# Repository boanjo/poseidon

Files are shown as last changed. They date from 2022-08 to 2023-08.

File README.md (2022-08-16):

# poseidon
Poseidon - is a modular control setup for your garden pond for sensors and switches. Monitoring is done with the TICK stack (Telegraf, Influxdb, Chronograf and Kapacitor) accompanied by a python Flask webserver for the control and quick overview. All is (in my setup) running on a raspberry PI 4. The influxdb creates some CPU spikes but there is plenty of power over to serve the relevant stuff and UI experience is smooth. I used to run it on a RPI 3B but that was pushing the limits a bit (both memory and CPU) at least for the influxdb database.

The application is built mainly of 5 parts (For a deeper description use the READMEs below) but each individual service can be used standalone with some tweaking:
* [Fishfeeder](https://github.com/boanjo/poseidon/tree/main/fishfeeder/README.md) 
* [Water Control ](https://github.com/boanjo/poseidon/tree/main/water_control/README.md) with level and tap (including watering of the garden plants)
* [Web Server](https://github.com/boanjo/poseidon/tree/main/web_app/README.md) instance
* [Water Quality - Atlas scientific sensors](https://github.com/boanjo/poseidon/tree/main/water_quality/README.md) in custom casing and mounted in a Sieve filter
* [Pond Control](https://github.com/boanjo/poseidon/tree/main/pond_control/README.md) which is the "controller" in this setup 

The interaction with the pond is mainly done via the web app where you can control timers or interactive feeding, water on/off etc. For more details and long term trends you have that in the Chronograf or Grafana which visualize the DB data. Chronograf has a few nice predefined dashboards both for RPI resource (CPU, mem,...) usage and also the sensor values from the pond. Kapacitor is not really used at all and you can disable it if wanted as the pond_control is doing some of it's work. Telegraph is mainly used to collect the resource usage.

Overview!

All services are communicating through a MQTT (mosquitto) gateway (also running on the RPI). The Fishfeeder firmware is running on a Wemos D1 mini over wifi, the water quality on a Arduino UNO and the water control on an Arduino Nano 

The services are started using docker composer so you can update the docker-compose.yml to suite your needs. 

Not all days are sunny!

Pond!

## Howto start
* First you need to decide if you want to have all the parts and sensors. All services should be ok with that no values at all are bing pushed but there might be hardcoded assumptions (like in the web app) that you at some point will get ORP and PH etc.
* If you are building sensors like the water_control or simply the fishfeeder now is the time to do so and to program it's firmware (see each README for details). The fishfeeder hooks up over wifi and the water_quality and water_control with Arduino UNO and Nano. One reason for selecting different Arduinos is to get determensitic names at boot (i.e. so they don't get mixed) due to race conditions. This could have been solved in other ways but it's a good bonus worth knowing about.
* Now you can build and start your services (you need to install docker and docker-compose on the RPI, use something like: https://dev.to/elalemanyo/how-to-install-docker-and-docker-compose-on-raspberry-pi-1mo):

<pre><code>
  docker-compose build   #build all services based on the yml file
  docker-compose -d up   #Here you start all the services in the docker-compose.yml file daemonized so even if you exit your shell they will continue to live and start on boot
  docker ps              #check all the services up and runnig
  docker-compose logs -f #Follow the logging from all the services
</code></pre>

Here is a YouTube video explaining the Poseidon setup: https://youtu.be/6Q65v6jY_po
Here is the full Poseidon playlist: https://www.youtube.com/watch?v=6Q65v6jY_po&list=PL4uTTzIGocpXYQ4JUedOa0raxNH4VkoVa

## More details
I have 2 dashboards setup for Chronograf (one detailed/all data for the last 3 days and one downsampled for the last moth). It's quite easy to add your own graphs based on the influxdb data, but if you want to reuse them you can:
* Download the json files from the repo and drag and drop them in Chronograf under "Dashboards->Import Dashboards".
* Headless from your RPI you can install curl and then import one json a t a time with:
  * curl -i -X POST -H "Content-Type: application/json" http://localhost:8888/chronograf/v1/dashboards -d pc_dashboard.json
  * curl -i -X POST -H "Content-Type: application/json" http://localhost:8888/chronograf/v1/dashboards -d pc_dashboard_downsampled.json

Here is what you can get from the detailed dashboard (retention period 3 days):
Dashboard

Here is what you can get from the resource (Click in Chronograf in the left column "Host List"):
Host resource usage

Poseidon is licensed under GNU General Public License v3.0 or later

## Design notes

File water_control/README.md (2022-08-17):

# Water Control

The water control is built from a water level sensor (2 alternatives below) a few solenoids (one for the pond and pone for the garden plants micro drip system) for adding tap water and also measuring the water amount used. You need to print a few parts with your 3D printer. I'm using PETG with support on most of the printouts so that it can resist the outdoor UV. I.m just doing basic sanding (paper and file) and then put some spray paint on it to look nice.

For the water level control i have 2 differnt solutions, where the first one is what i currently use (see alternative 2 at the bottom - most parts are common):
## Alternative 1: KUS liquid level sensor
The sensor has a magnet in the floating piece which controls reed switches inside the steel rod to output different resistance at differnt levels. I'm using European standard sensor where the resistance is between 0-180ohm and it's priced at ~20$. To make the two solutions compatible i've added a resistance to the outer two pins as the fixed reference in a voltage divider (see below). Even if the accuracy for the sensors is 21mm (the step between the reed switches) you can make the level full/low toggle on a +-5mm accuracy due the nature of the reed switches. I.e. when the level goes down the reed switch will continue to be activated for maybe 5mm until the next lower one gets activated. Same goes in the other direction so this means that the accuracy for the range where values toogle between is 10mm or less. So just set min and max between those levels and you are good to go. Of course if you want to use the sensor for detailed monitoring of the level you will not get better than 21mm accuracy and you should probably go for the etape solution.  
KUS liquid level sensor

An Arduino Nano is used for the regulated loop and has some auto cut off for the water in some suspicious situations. Basically a high and low threshold is built in (and can be changed) and then the water control will try to keep that level. The levels are measured at a frequency of every 3:d second (can be changed) and passes through a ringbuffer of 8 where the average is calculated from. This applies to both solutions and even if you can set the ringbuffer to something smaller you risk getting ping-ponging in case of movements from the fish or strong winds. 

Some plumbing needed for the water, 2 solenoids (2x7$) and water flow sensor (~15$). To get a good pressure and a filter i've integrated it with a gardena micro drip system (~25$). And the plumbing parts are probably another 30-40$.
Plumbing

I've hidden the water control parts in 2 cement pots. This part of the system can be left out, and the only thing i do before winter time is to attach the compressor, open all the solenoids and blow the system "clean" of water. 
Concrete

Pretty easy to hide
Hidden

For programming of the firmware i've installed the platformio cli version https://docs.platformio.org/en/latest/core/index.html on the raspberry pi. I.e. i'm running an ssh connection with for example putty or mobixterm to the RPI and edit the SW using emacs, git, ino etc directly into the cloned repo. You need to stop the docker service that is communicating with the arduino to release the serial port (e.g. "docker stop poseidon_water_control_1"), then build and upload (see the CMD file for the sequence i use "source CMD" to execute) and then start the service again ((e.g. "docker start poseidon_water_control_1").

The firmware basically consists of and serial command input handler to be able to act on commands from the controller, setting levels etc. Then there is a small interrupt function that calculates any triggers from the water flow sensor and then in the loop a (quite sketchy ;-)) conversion of ticks into liters (you probably need to calibrate it to get as good flow accuracy). The percentage level of the KUS or etape sensor is done using a voltage divider. By using the ADC value (max 1024) you can then get the relative % (For more details see the source code). Once the level reaches a low point this triggers (if auto level is on) the water solenoid to open. Once the max is reached the water stops to fill again. The sensor blindly updates all values and states every sample period which is set to default every 3 seconds (or immediately if ack is requested).   
Voltage Divider

See stl_step folder models (download and edit STEP or just print STL):
Model to mount KUS level sensor

On the RPI there is a serial2mqtt.py application running and as the name indicates it bridges between the serial commands and the mqtt GW.

You need a small proto baord (the Adafruit Perma-Proto 1/2 Sized Breadboard is a great fit) for all the connections and the Arduino nano, schematics here. The RPI needs a standard RPI4 power supply (i've cut mine with a pair of GX12 2 pin connectors to get it into the box). You also need a 12 transformer for the solenoids (cut in the same way but with a 3 pin to not make any misstake). Then there is one 4 pin GX12 connector for the KUS or etape.
Schematic

Notice the mounted resistor of 100ohm (needed for the voltage divider) inside the KUS level sensor to make it pin compatible with the etape (Pin 1 & 4 for Rref and middle 2,3 for Rsense i.e. the variable part)
Resistor

Everything is hosted in the same box as the RPI4
Box

Here is a video covering the Water Control with coding and usage: https://youtu.be/Q5HgJ9Mg1no

Here is a YouTube video explaining the KUS liquid level setup: https://youtu.be/7Df8thEyxGE
Here is the full Poseidon playlist: https://www.youtube.com/watch?v=6Q65v6jY_po&list=PL4uTTzIGocpXYQ4JUedOa0raxNH4VkoVa

## Alternative 2: Milone technology etape
The sensor is quite sensitive and this is why i have move to the float switch solution instead. I love the etape due to it's accuracy but it has broken down on me a few time too many (resistance all of a sudden goes off the datasheet range like max 2.2k is all of a sudden 9k etc) and you of course need something robust when dealing with water.
Etape

3D printed parts

See stl_step folder models (download and edit STEP or just print STL):
Model to mount etape level sensor

Here is a YouTube video explaining the etape liquid level setup: https://youtu.be/k4SEj0wbtEo

Poseidon is licensed under GNU General Public License v3.0 or later

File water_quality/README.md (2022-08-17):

# Water Quality

The water quality is monitored with a set of sensors or probes from Atlas Scientific: Temperature, PH, ORP, DO and EC probes are connected to the carrier boards mounted on a Tentacle T1 MKII. The firmware is running on an Arduino UNO 

Atlas sensors with mounting in the Sieve filter

If you don't want to go all in (these sensors + carrier boards cost in the range of $150 to much more) i think the PH and ORP are the most valuable measurments to have. I rarely look at the EC or DO values. Bu that is also because i live in a place in Sweden where the tap water quality is very good. So hard to make any recommendations there but you know my thinking at least. The temperature sensor seems good even if you can make a cheaper solution yourself.

On the RPI there is a serial2mqtt.py application running and as the name indicates it bridges between the serial commands and the mqtt GW.

The Arduino UNO firmware continously collects all the sensor values every 3 seconds and the data is continously pushed to the DB via the MQTT GW, see dashed route red:
Sensor route

For programming of the firmware i've installed the platformio cli version https://docs.platformio.org/en/latest/core/index.html on the raspberry pi. I.e. i'm running an ssh connection with for example putty or mobixterm to the RPI and edit the SW using emacs, git, ino etc directly into the cloned repo. You need to stop the docker service that is communicating with the arduino to release the serial port (e.g. "docker stop poseidon_water_quality_1"), then build and upload (see the CMD file for the sequence i use "source CMD" to execute) and then start the service again ((e.g. "docker start poseidon_water_quality_1").

You can monitor the sensor values eiter in the web_gui which shows the sensor values in real time but also with min and max range on the right side. You can also follow longer trends in either Grafana or Chronograf. This is from my default dashboards you can also import from the poseidon root dir.
Sensor Details

See stl_step folder models (download and edit STEP or just print STL):

The Tentacle T1 MKII is a great board for the carrier boards and the sensors and i really recommend it. I've made a small box (not water proof) with both a plexiglass front and a solid one.
Tentacle T1 MKII box model
Tentacle T1 MKII box
Hidden electronics

The mounting is tailored for my Sieve filter and works really well. Some of the Atlas sensors need to have a water flow to give accurate readings so this is perfect. It's also a pretty good way to hide the cables
Atlas sensors mounting model
Sieve filter

Here is a YouTube video explaining the sensors, 3D models and code for the water quality setup: https://youtu.be/J5xhtjKq1kM
Here is the full Poseidon playlist: https://www.youtube.com/watch?v=6Q65v6jY_po&list=PL4uTTzIGocpXYQ4JUedOa0raxNH4VkoVa

Poseidon is licensed under GNU General Public License v3.0 or later

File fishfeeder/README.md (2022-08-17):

# Fishfeeder

I have built a number of feeders for my koi fishes over the year (first one in 2005 ;-)) but now i i finally found a way that i think is a good balance between price, quality and build effort. You need to have a 3D printer (i guess you can order them from a printshop too). There are PETG material needed for maybe $20-30, a simple DC continously rotating servo for ~$10, a wemos D1 mini for ~$8 some sewer pipe parts (or if you want your own tank) for another ~$15. So in total you should be able to produce it with ~$50. The pellets screw is designed for 3mm pellets (it might work with other sizes but i don't know since i only use 3mm myself).

The water control is built from a water level sensor (2 alternatives below) a few solenoids (one for the pond and pone for the garden plants micro drip system) for adding tap water and also measuring the water amount used. You need to print a few parts with your 3D printer. I'm using PETG with support on most of the printouts so that it can resist the outdoor UV. I.m just doing basic sanding (paper and file) and then put some spray paint on it to look nice.

The feeder next to the reed makes it more fun for the fishes (they are hunting like crazy in the reed) but also good to avoid getting too fast into the skimmer.
The feeder
The feeder2

Here are the parts for the feeder:
PVC pipes and some 3D prints

Basic operation is like a pellets screw. The screw has a loose fit in the cylinder to reduce the fricton and there is no problem for the DC servo to rotate, pulling KOI pellets from the PVC tube.
Basic operation

The full unit except the PVC tube:
Feeder kit

I didn't rough the surface enough the first time, but now it's good. Ideally add some PVD primer or other coler with specialized adhesion.
PVC pipes and some 3D prints

See stl_step folder models (download and edit STEP or just print STL):
Fishfeeder model

Closeup

Here is a YouTube video explaining the 3D models and code for the fishfeeder: https://youtu.be/I_7Ob8AsT4w
Here is the full Poseidon playlist: https://www.youtube.com/watch?v=6Q65v6jY_po&list=PL4uTTzIGocpXYQ4JUedOa0raxNH4VkoVa

The firmware that you need to upload to the Wemos D1 mini can be done from the same RPI using a micro USB cable (unless you want to install platformio gui or cli on your laptop/desktop). The source code is quite simple and mainly default sketch for connecting to your Wifi, connect to a MQTT server and then to just listen on incoming feeding requests where the DC servo is stepped accordingly. It also reports back when ready or listen to ack requests. In order to get a specific amount in milliliter or such then just tune that with your specific fishfood (as that might differ with different pellets) to see how many steps that match. With a fishfeeder you have the luxury of feeding less but more frequently :-). 9 steps on the DC servo is the equivalent of one tablespoon i.e. 15ml so rougly 1.5ml per step. The default value in the web_app when feeding interactively is only 3 (change if you want to (in the web_app/app.py)) so one teaspoon 5ml.
* Change the WIFI settings for your router in Credentials.h or you will get a compilation error (just remove the #error when done)
* Update the mqtt_server ip address in main.cpp or you will get a compilation error (just remove the #error when done)

You don't need any board and very little soldering. Basically the 3 wires on the wemos, see schematic. The rest is mounted on the printed mounting and a 2 pol terminal connector
Schematic
Mounting

Poseidon is licensed under GNU General Public License v3.0 or later

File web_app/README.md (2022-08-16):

# Poseidon Web App

The web app is built upon python flask that is running on the RPI4. This is more than enough for a low number of users (i assume you don't expose your pond control for thousands of users ;-). Otherwise flask should be fronted with a proper WSGI webserver like nginx.

The web app uses both the influxdb and mqtt to gather the data presented in the GUI. While active it listens to new sensor values (i.e. real time) but also shows the min and max values today for all sensors. 

If you press the Debug button in the right top corner you will be adding all the raw MQTT messages that are coming on the bus. Press it once more to toggle off or your web gui will be sluggish as it just appends divs to the page. The chronograf dashboards can be reached via the top left button

To open the dashboard just navigate to the ipaddress and the port you choose to expose in the docker-compose.yml (under web_app ports).  i.e. http://localhost:8080
Dashboard

As the button says "Timers" i guess it's no surprise that here you can modify the timers/alarms for feeding the fishes, starting sprinklers etc.
Timers

Feel free to update the web app to your liking. I wanted it clean so there are not so much visual bells and whistles. See it as a boilerplate that does the job.

Here is a YouTube video giving an overview of the code for the web_app: https://youtu.be/K_MTeVfbo9E
Here is the full Poseidon playlist: https://www.youtube.com/watch?v=6Q65v6jY_po&list=PL4uTTzIGocpXYQ4JUedOa0raxNH4VkoVa

Poseidon is licensed under GNU General Public License v3.0 or later

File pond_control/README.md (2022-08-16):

# Pond Control

This is a small piece of python software that continously keep track of timeouts (alarms) to feed or turn on water etc. It also interacts with the influxdb and stores subscribed mqtt topics (all pc/# topic) into the database. This is something that you normally can make with the telegraph service but the configuration for it got too complicated so it was easier to implement in a few lines of python. So even if it is small it's the most central piece of the SW stack i.e. the controller. 

Overview

Poseidon is licensed under GNU General Public License v3.0 or later

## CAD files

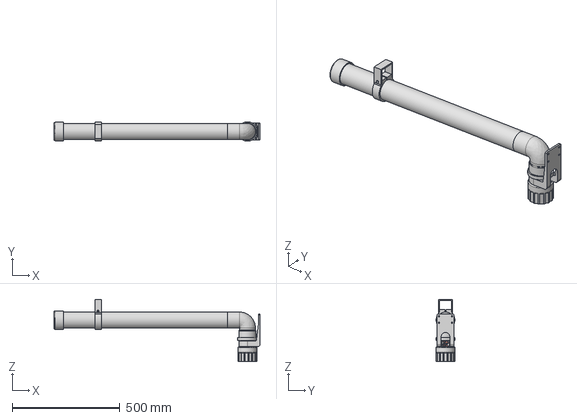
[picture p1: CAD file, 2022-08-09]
fishfeeder/stl_step/FishFeeder Tube straight v10.step
954.6 x 90.0 x 288.0 mm

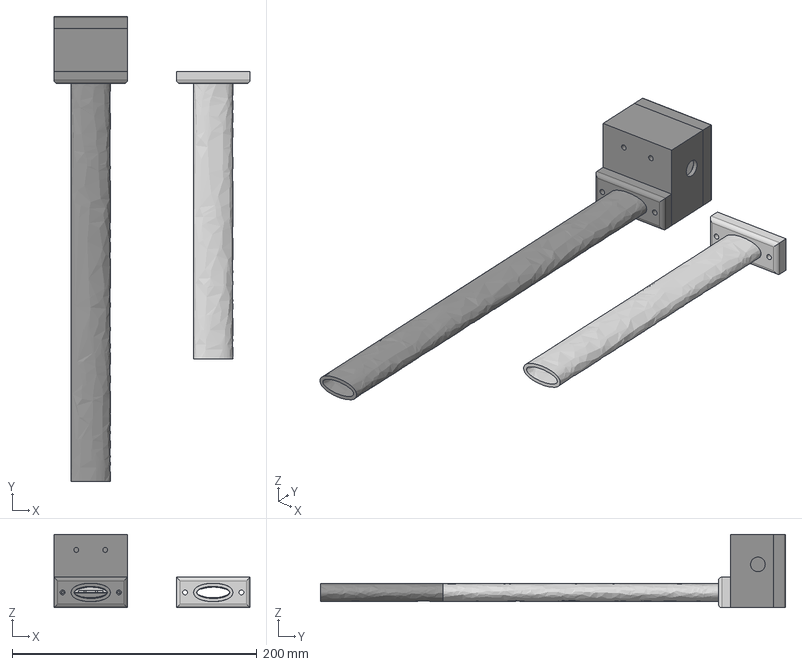
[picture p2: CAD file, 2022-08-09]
water_control/stl_step/Water Level Sensor v10.step
160.0 x 380.0 x 60.0 mm

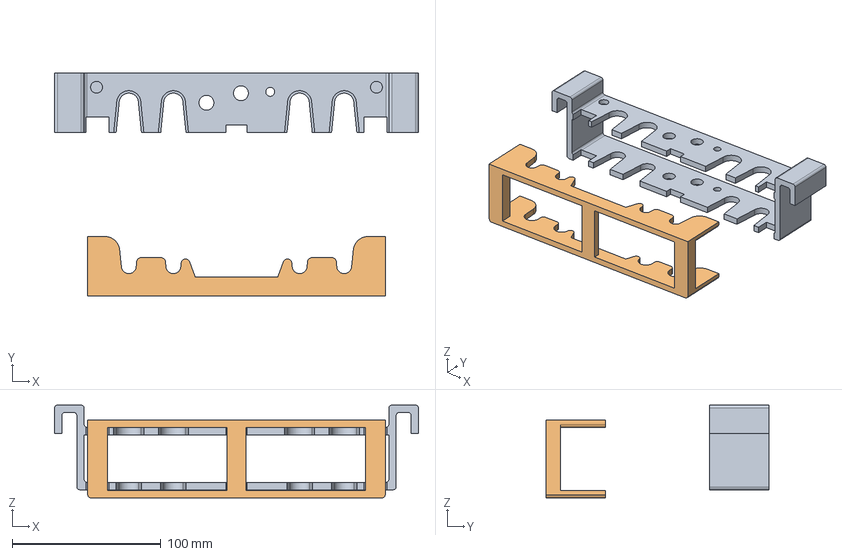
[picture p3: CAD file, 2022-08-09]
water_quality/stl_step/Probe mounting v1.step
245.0 x 150.0 x 62.5 mm

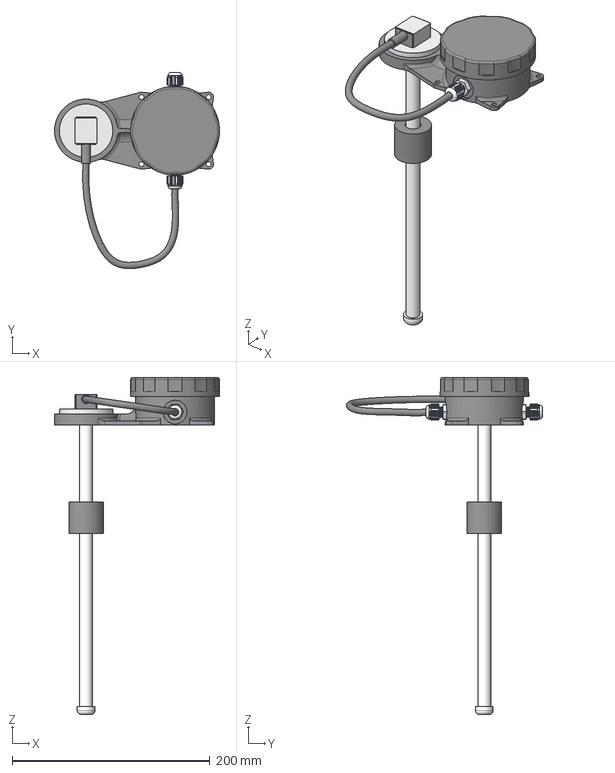
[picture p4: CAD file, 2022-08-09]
water_control/stl_step/KUS level sensor v9.step
167.0 x 198.6 x 341.0 mm

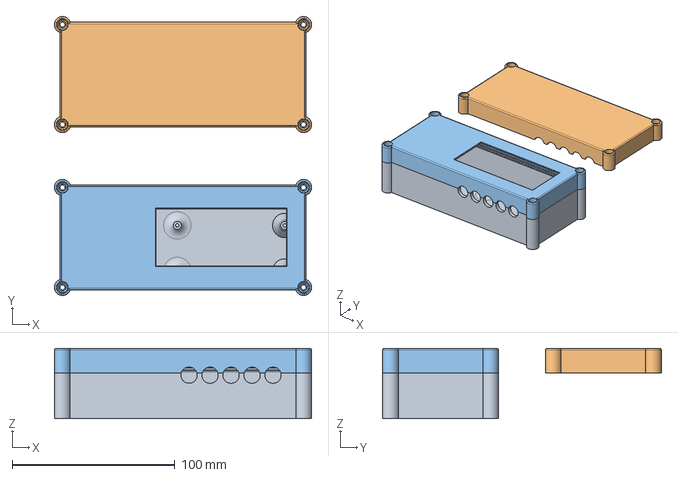
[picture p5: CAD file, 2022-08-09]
water_quality/stl_step/water_quality v5.step
158.0 x 171.3 x 43.0 mm

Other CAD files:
fishfeeder/stl_step/FishFeeder Tube straight v10.stl
water_control/stl_step/KUS level sensor v9.stl
water_control/stl_step/Water Level Sensor v10.stl
water_quality/stl_step/Probe mounting v1.stl
water_quality/stl_step/water_quality v5.stl

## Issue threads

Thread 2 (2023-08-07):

fishfeeder not working well with 6mm pellets

dhaude, 2023-08-07:
@boanjo
I already started my own design based on the sewer pipes you are using as well. After finding your project I stopped my design activities and build the feeder completely on your design.
I finished it during the weekend and started first tests today.
Unfortunately I am using 6mm pellets and they cause the screw to jam and the DC-Motor is not strong enough to "crack" them.
So 2 things I've in mind now:
1. I ordered a bag 3mm pellets - hoping that those are transported smoothly
or
2. I kindly ask you to provide me with you original CAD-Design Files in order to adopt the design to the 6mm pellets - any chance?

Thank you so much for sharing your 'poseidon' project - I really like it!

boanjo, 2023-08-08:
@dhaude btw did you see the fishfeeder/stl_step/FishFeeder Tube straight v10.step file? I forgot i had already provided the model. Import the step file in fusion 360 and you should be good to go. If it still doesn't work i'm sure the 360 files can be shared. Let me know how it goes!

dhaude, 2023-08-08:
@boanjo - Ah, OK, I will try that.
My strategy is the following: I will get some 3mm pellets by tomorrow and if this goes well - I'll change to those without any changes.
I also ordered a 360 degree Servo with much higher torque and will check this as well.
Only if that will not do the job - I'll try to change the dimensions of the mechanics.
For your information: I added OTA support to your code - so debug and small SW changes can now be loaded via WiFi without going out and opening the feeder.
I also found a small Software flaw in your code - some double quotes for `clientId` were missing.
Should be:
#endif
    String payload = "{\"type\":\"periodic_wifi_mqtt\",";
    payload += "\"micros\":";
    payload += micros();
    payload += ",\"rssi\":";
    payload += rssi;
    payload += ",\"cnt_reconnect\":";
    payload += cntReconnectAttempt;
    payload += ",\"client\":\"";
    payload += clientId;
    payload += "\"}";

Thanks again for this project and have a nice day.

dhaude, 2023-08-08:
just noticed that the backslashes were not shown:

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

Closed 2023-08-09.

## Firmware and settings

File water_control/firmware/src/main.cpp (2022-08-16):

//**************************************************************************************
// Poseidon is licensed under GNU General Public License v3.0 or later
//**************************************************************************************

#include <Arduino.h>
#include <stdlib.h>
#include <ctype.h>

#define LEVEL_SENSOR_KUS   0
#define LEVEL_SENSOR_ETAPE 1

long levelSensorType = LEVEL_SENSOR_KUS;
#define WATER_LEVEL_PIN A0

// For a KUS reed swith type of sensor it's optimal to find a wanted level between two reistances (the sensor has a granularity
// of 20-22mm). If you select it carfully you can still accomplish a threshold that is within +-5mm or so. In the example below
// i have a 300mm KUS sensor which then has 13 steps(0-192 fixed resistances. so the value i want to stay at is just when it
// toggles to the second highest level 91.5% and the 3:d highest level is at 86.5%. hence i have selected min and max level as
// two values inbetween. The reed switched has a built in hysteresis. So when a reed switch gets activated it will continue to
// hold slightly longer until the next switch gets activated.
// Operations will then be: we fill until the 91.5% is reached and then stop. When the level is slowwly decreasing (remove water
// or waporize) iit will continue to hold the level at 91.5% for another 5-10mm and then toggle to 86.5%. We will then be below the
// min and once again we will fill up again. I.e. we can achieve 5-10 mm operations accuracy even if it is only 20-22mm for the
// actual sensor.
long waterLevelLow = 88;
long waterLevelHigh = 89;

#define FLOW_SENSOR_PIN 2
#define SPRINKLER_1_CONTROL_PIN 6
#define WATER_CONTROL_PIN 5

#define STATE_WATER_OFF 0
#define STATE_WATER_ON  1

#define NO_OF_LEVEL_AVERAGE_ITEMS 8

#define MODE_WATER_MANUAL 0
#define MODE_WATER_AUTOMATIC 1


float levelArray[NO_OF_LEVEL_AVERAGE_ITEMS];
long levelAvgCnt = 0;
byte waterMode = MODE_WATER_AUTOMATIC;
byte waterState = STATE_WATER_OFF;
byte sprinkler1State = STATE_WATER_OFF;
unsigned long previousMillis = 0;
unsigned long interval = 3000;
String inputString = ""; // a string to hold incoming data

volatile uint32_t flowPulses = 0;
volatile uint8_t lastFlowPinState = LOW;
long seqNo = 0;
// Interrupt is called once a millisecond, looks for any pulses from the sensor!
SIGNAL(TIMER0_COMPA_vect)
{

  uint8_t x = digitalRead(FLOW_SENSOR_PIN);

  if ((x == HIGH) && (lastFlowPinState == LOW))
  {
    //low to high transition!
    flowPulses++;
  }
  lastFlowPinState = x;
}

void useInterrupt(boolean v)
{
  if (v)
  {
    // Timer0 is already used for millis() - we'll just interrupt somewhere
    // in the middle and call the "Compare A" function above
    OCR0A = 0xAF;
    TIMSK0 |= _BV(OCIE0A);
  }
  else
  {
    // do not call the interrupt function COMPA anymore
    TIMSK0 &= ~_BV(OCIE0A);
  }
}

void setup(void)
{
  Serial.begin(115200);
  digitalWrite(WATER_CONTROL_PIN, LOW);
  pinMode(WATER_CONTROL_PIN, OUTPUT);

  digitalWrite(SPRINKLER_1_CONTROL_PIN, LOW);
  pinMode(SPRINKLER_1_CONTROL_PIN, OUTPUT);

  pinMode(WATER_LEVEL_PIN, INPUT);

  pinMode(FLOW_SENSOR_PIN, INPUT);
  digitalWrite(FLOW_SENSOR_PIN, HIGH);
  lastFlowPinState = digitalRead(FLOW_SENSOR_PIN);

  useInterrupt(true);

  Serial.println("Starting!");
}

int getSerialValue(String str)
{
  String subStr = str.substring(str.indexOf(",") + 1, str.length());
  return subStr.toInt();
}

void printState(bool state) {
  if (state)
    Serial.print("on");
  else
    Serial.print("off");
}

void loop(void)
{
  const byte strLen = 8;
  char litersStr[strLen];
  char levelStr[strLen];
  float waterLevel;
  float waterLevelAvg = 0;
  char inChar;
  boolean ack_requested = false;
  
  // USB HW serial
  if (Serial.available() > 0)
  {
    inChar = Serial.read();

    if (inChar == '{')
    {
      inputString = "";
    }
    else if (inChar == '}')
    {
      if (inputString.length() > 0)
      {

        if (inputString.indexOf("water_level_low") != -1)
        {
          waterLevelLow = getSerialValue(inputString);
        }
        else if (inputString.indexOf("water_level_high") != -1)
        {
          waterLevelHigh = getSerialValue(inputString);
        }
        else if (inputString.indexOf("ack_request") != -1)
        {
          seqNo = getSerialValue(inputString);
	  ack_requested = true;
        }
        else if (inputString.indexOf("water") != -1)
        {
	  String subCmd = inputString.substring(inputString.indexOf(",")+1, inputString.length());
          if (subCmd.indexOf("off") != -1)
          {
            digitalWrite(WATER_CONTROL_PIN, LOW);
            waterState = STATE_WATER_OFF;
          }
          else if (subCmd.indexOf("on") != -1)
          {
            digitalWrite(WATER_CONTROL_PIN, HIGH);
            waterState = STATE_WATER_ON;
          }
        }
        else if (inputString.indexOf("auto_level") != -1)
        {
	  String subCmd = inputString.substring(inputString.indexOf(",")+1, inputString.length());

	  if(subCmd.indexOf("off") != -1)
          {
            waterMode = MODE_WATER_MANUAL;
          }
          else if (subCmd.indexOf("on") != -1)
          {
            waterMode = MODE_WATER_AUTOMATIC;
          }
        }
        else if (inputString.indexOf("sprinkler1") != -1)
        {
	  String subCmd = inputString.substring(inputString.indexOf(",")+1, inputString.length());
	  
	  if(subCmd.indexOf("off") != -1)
          {
            digitalWrite(SPRINKLER_1_CONTROL_PIN, LOW);
            sprinkler1State = STATE_WATER_OFF;
          }
	  else if(subCmd.indexOf("on") != -1)
          {
            digitalWrite(SPRINKLER_1_CONTROL_PIN, HIGH);
            sprinkler1State = STATE_WATER_ON;
          }
        }

        inputString = "";
      }
    }
    else
    {
      // add it to the inputString:
      inputString += inChar;
    }
  }

  unsigned long currentMillis = millis();

  // Handle wrap around
  if (currentMillis < previousMillis)
  {
    previousMillis = currentMillis;
  }
  if (((currentMillis - previousMillis) > interval) || ack_requested)
  {
    // save the last time you blinked the LED
    previousMillis = currentMillis;

    // Calculate amount of added water in liters
    float liters = flowPulses;
    liters /= 8.1;
    liters -= 6;
    liters /= 60.0;

    if (liters < 0)
      liters = 0;
    dtostrf(liters, 7, 1, litersStr);

    // Read the KUS or etape voltage divider
    int analogLevelValue = analogRead(WATER_LEVEL_PIN);

    if(levelSensorType == LEVEL_SENSOR_KUS) {
      // KUS European level switch goes between 0-192 (or actually 0-180 according to datasheet) ohm (192 100% full)
      // Voltage divider tells us R2/(R1+R2) where R2 is the KUS variable resistance
      // and R1 is the fixed 100ohm resistance
      // So the max analog read would be 192/(192+100)*1023=673
      // So to get the percentage fill level 0-100% we can divide the analog value
      // with 6.73
      
      waterLevel = analogLevelValue / 6.73;
    } else {

      // milonetech etape (use RSense i.e. middle two pins as R2 and outer two pins (RRef) as R1
      // For an empty level (i.e. no water contact on Rsense) the two resistances should be roughly the same
      // 2.2k/(2.2k+2.2k)*1023=512 
      waterLevel = 100.0 - (analogLevelValue / 5.12);

      // As an example a completly submerged etape will have a resistance of 400ohm on RSense. This means that
      // the fill level will never reach 100% (analogLevelValue will show ~93 i.e. waterLevel = 82% (100-(93/5.12)
      // Select the level min max (waterLevelLow, waterLevelHigh) thresholds accordingly
      
      if(waterLevel < 0.0) {
	waterLevel = 0.0;
      }
    }
    
    levelArray[levelAvgCnt % NO_OF_LEVEL_AVERAGE_ITEMS] = waterLevel;
    levelAvgCnt++;

    if (levelAvgCnt >= NO_OF_LEVEL_AVERAGE_ITEMS)
    {
      for (int i = 0; i < NO_OF_LEVEL_AVERAGE_ITEMS; i++)
      {
        waterLevelAvg += levelArray[i];
      }

      waterLevelAvg = waterLevelAvg / NO_OF_LEVEL_AVERAGE_ITEMS;

      // Something is fishy, better turn off the auto mode too
      if (waterLevelAvg > 95)
      {
	if(waterMode == MODE_WATER_AUTOMATIC)
	{
	  waterMode = MODE_WATER_MANUAL;

	  digitalWrite(WATER_CONTROL_PIN, LOW);
	  waterState = STATE_WATER_OFF;
	}
      }

      if (waterMode == MODE_WATER_AUTOMATIC)
      {
        if ((waterLevelAvg < waterLevelLow) && (waterState == STATE_WATER_OFF))
        {
          digitalWrite(WATER_CONTROL_PIN, HIGH);
          waterState = STATE_WATER_ON;
        }
        else if ((waterLevelAvg > waterLevelHigh) && (waterState == STATE_WATER_ON))
        {
          digitalWrite(WATER_CONTROL_PIN, LOW);
          waterState = STATE_WATER_OFF;
        }
      }
    }

    dtostrf(waterLevelAvg, 5, 1, levelStr);

   
    //######### SERIAL SEND ################

    Serial.print("{analog_level_value,");
    Serial.print(analogLevelValue);
    Serial.println("}");

    Serial.print("{flow,");
    for(int i = 0; i < strLen; i++) {
      if(litersStr[i] == '\0')
	break;
      if(!isspace(litersStr[i])) {
	Serial.print(litersStr[i]);
      }
    }      
    Serial.println("}");
    Serial.print("{level,");
    for(int i = 0; i < strLen; i++) {
      if(levelStr[i] == '\0')
	break;
      if(!isspace(levelStr[i])) {
	Serial.print(levelStr[i]);
      }
    }      
    Serial.println("}");

    Serial.print("{auto_level,");
    printState(waterMode == MODE_WATER_AUTOMATIC);
    Serial.println("}");

    Serial.print("{water,");
    printState(waterState == STATE_WATER_ON);
    Serial.println("}");

    Serial.print("{sprinkler1,");
    printState(sprinkler1State == STATE_WATER_ON);
    Serial.println("}");

    if(ack_requested) {
      Serial.print("{ack,");
      Serial.print(seqNo);
      Serial.println("}");
    }
  }
}

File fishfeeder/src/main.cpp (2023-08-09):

//**************************************************************************************
// Poseidon is licensed under GNU General Public License v3.0 or later
//**************************************************************************************

#include <ESP8266WiFi.h>
#include <PubSubClient.h>
#include <Credentials.h>

#define DEBUG 1
int servoPin = D3;

#error Remove this line once you have updated the IP address below
const char *mqtt_server = "192.168.1.9"; // @TODO change this to the IP of your MQTT server


const char *topic = "pc";                // The mqtt root topic
String pubTopic;

long timeBetweenMessages = 1000 * 5 * 1;
long timeBetweenReconnectAttempts = 1000 * 5;

WiFiClient espClient;
PubSubClient client(espClient);
long lastMsg = 0;
long lastReconnectAttempt = 0;
long cntReconnectAttempt = 0;
String clientId = "fishfeeder";
int status = WL_IDLE_STATUS; // the starting Wifi radio's status

void setup_wifi()
{
  delay(10);
  // We start by connecting to a WiFi network
  Serial.println();
  Serial.print("Connecting to ");
  Serial.println(WIFI_SSID);
  WiFi.begin(WIFI_SSID, WIFI_PW);
  while (WiFi.status() != WL_CONNECTED)
  {
    delay(500);
    Serial.print(".");
  }
  Serial.println("");
  Serial.println("WiFi connected");
  Serial.println("IP address: ");
  Serial.println(WiFi.localIP());
}

#define MAX_QUEUE_ITEMS 8
int feedIndex = 0;
int insertIndex = 0;
int numFeedItems = 0;
int feedQueue[MAX_QUEUE_ITEMS];
boolean stateFeeding = false;
int pulseCount = 0;
long totalFeedCount = 0;
long pinStartMicros = 0;

void callback(char *topic, byte *payload, unsigned int length)
{
  Serial.print("Message arrived [");
  Serial.print(topic);
  Serial.print("] ");
  String msg = "";
  for (unsigned int i = 0; i < length; i++)
  {
    //Serial.print((char)payload[i]);
    msg += (char)payload[i];
  }
  Serial.println(msg);

  // Switch on the LED if an 1 was received as first character
  if (strcmp(topic, "pc/fishfeeder/in/feed") == 0)
  {
    if (msg.indexOf("{value:") != -1)
    {
      int value = atoi(msg.substring(msg.indexOf(":") + 1, msg.indexOf("}")).c_str());
      if (numFeedItems < MAX_QUEUE_ITEMS)
      {
        Serial.print("Feeding! numFeedItems = ");
        Serial.println(numFeedItems);

        // x8 to translate ml to pulses (depending on the feeding screw dimension)
        feedQueue[insertIndex] = value * 8;
        numFeedItems++;
        insertIndex++;
        if (insertIndex >= MAX_QUEUE_ITEMS)
        {
          insertIndex = 0;
        }
        Serial.print("Feeding!");
      }
      else
      {
        Serial.println("Max Queue reached!!!!");
      }
    }
    else
    {
      Serial.println("Unknown sub command");
    }
  }
  else if (strcmp(topic, "pc/fishfeeder/in/ack_request") == 0)
  {
    if (msg.indexOf("{value:") != -1)
    {
      int value = atoi(msg.substring(msg.indexOf(":") + 1, msg.indexOf("}")).c_str());
      String topic = pubTopic;
      topic += "/ack";
      String valStr = "{\"value\":";
      valStr += value;
      valStr += "}";
      client.publish((char *)topic.c_str(), (char *)valStr.c_str(), true);
    }
    else
    {
      Serial.println("Unknown sub command");
    }
  }
  else
  {
    Serial.print("Unknown topic: ");
    Serial.println(topic);
  }
}

void reconnect()
{

  if (WiFi.status() != WL_CONNECTED)
  {
    setup_wifi();
  }

  Serial.print("Attempting MQTT connection...");

  // Attempt to connect
  if (client.connect(clientId.c_str()))
  {
    Serial.println("connected");
    // Once connected, publish an announcement...
    client.publish(topic, ("connected " + clientId).c_str(), true);
    // ... and resubscribe
    // topic + clientID + in
    String subscription;
    subscription += topic;
    subscription += "/";
    subscription += clientId;
    subscription += "/in/#";
    client.subscribe(subscription.c_str());
    Serial.print("subscribed to : ");
    Serial.println(subscription);
  }
  else
  {
    Serial.print("failed, rc=");
    Serial.print(client.state());
    Serial.print(" wifi=");
    Serial.print(WiFi.status());
    Serial.println(" try again in 5 seconds");
  }
}

void setup()
{
  pinMode(servoPin, OUTPUT);
  pubTopic += topic;
  pubTopic += "/";
  pubTopic += clientId;
  pubTopic += "/out";

  Serial.begin(115200);
  setup_wifi();
  client.setServer(mqtt_server, 1883);
  client.setCallback(callback);
}
int toggleCnt = 0;

boolean commandIsOngoing = false;
long lastKnownSwitchStateTime = millis();

//////////////////////////////////////////////////////////////////////////////////////////
// feed
/////////////////////////////////////////////////////////////////////////////////////////
void handle_feeding(long now)
{

  if (stateFeeding)
  {
    if (digitalRead(servoPin) == LOW)
    {
      if (micros() - pinStartMicros > 20000)
      {
        totalFeedCount++;
        pulseCount++;
        // Limit to max 100ml (800 pulses) at one time
        if ((pulseCount > feedQueue[feedIndex]) || (pulseCount > 800))
        {
          stateFeeding = false;
          feedIndex++;
          if (feedIndex >= MAX_QUEUE_ITEMS)
          {
            feedIndex = 0;
          }
          numFeedItems--;
          Serial.println("Feeding ready");
          String topic = pubTopic;
          topic += "/feeding_amount";
          String valStr = "{\"value\":";
          valStr += (totalFeedCount / 8);
          valStr += "}";
          client.publish((char *)topic.c_str(), (char *)valStr.c_str(), true);
#ifdef DEBUG
          Serial.print("Publish message: ");
          Serial.println(valStr);
#endif
        }
        else
        {
          digitalWrite(servoPin, HIGH);
          pinStartMicros = micros();
        }
      }
    }
    else
    {
      if (micros() - pinStartMicros > 2000)
      {
        digitalWrite(servoPin, LOW);
        pinStartMicros = micros();
      }
    }
  }
}
//////////////////////////////////////////////////////////////////////////////////////////
// loop
/////////////////////////////////////////////////////////////////////////////////////////
void loop()
{

  long now = millis();

  if (stateFeeding)
  {
    handle_feeding(now);
  }
  else if (numFeedItems > 0)
  {
    stateFeeding = true;
    pulseCount = 0;
    digitalWrite(servoPin, LOW);
    pinStartMicros = micros();
  }

  // confirm still connected to mqtt server
  if (!client.connected())
  {
    if (now - lastReconnectAttempt > timeBetweenReconnectAttempts)
    {
      lastReconnectAttempt = now;
      reconnect();
      cntReconnectAttempt++;
    }
  }
  if (client.connected())
  {
    client.loop();
  }

  if (now - lastMsg > timeBetweenMessages)
  {
    lastMsg = now;

    // print the received signal strength:
    long rssi = WiFi.RSSI();
#ifdef DEBUG
    Serial.print("RSSI:");
    Serial.println(rssi);
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

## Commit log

2021-07-15 Initial release with working sensors
2022-05-05 Added fishfeeder code
    [pond control 2.0.kicad_pcb, pond control 2.0.sch]
2022-08-09 Updated with new sensors
2022-08-09 Adding README andd images
    [FishFeeder Tube straight v10.step, FishFeeder Tube straight v10.stl, KUS level sensor v9.step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]
2022-08-10 Added schematics
    [fishfeeder.kicad_pcb, fishfeeder.sch, pond control 2.0.kicad_pcb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]
2022-08-17 STL files
2023-08-09 Missing quotation for client id
    [main.cpp]
